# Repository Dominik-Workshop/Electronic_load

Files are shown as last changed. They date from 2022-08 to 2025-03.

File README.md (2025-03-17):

# DC Electronic load

### More info about this project can be found on my channel: 
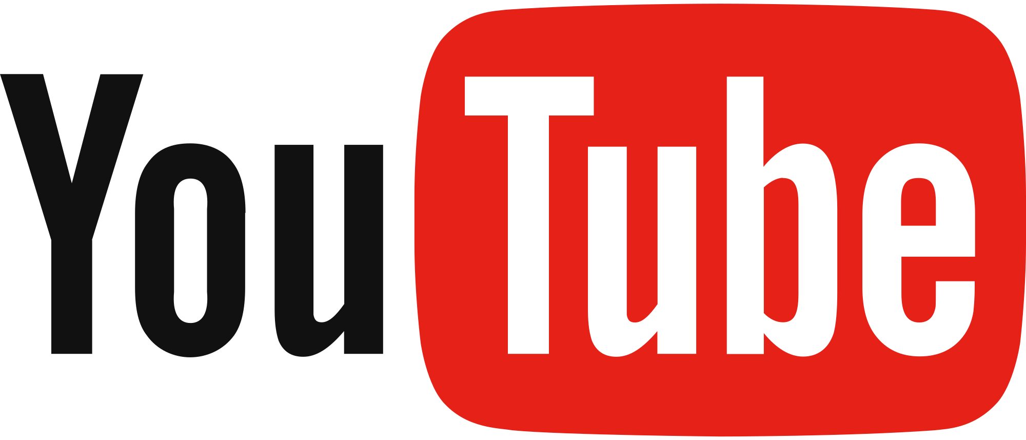
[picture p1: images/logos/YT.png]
 https://youtu.be/NScaRQj53l0

## Used tools:
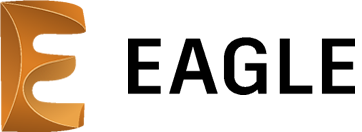
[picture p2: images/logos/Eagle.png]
 &nbsp;&nbsp;&nbsp;&nbsp; &nbsp;&nbsp;&nbsp;&nbsp; 
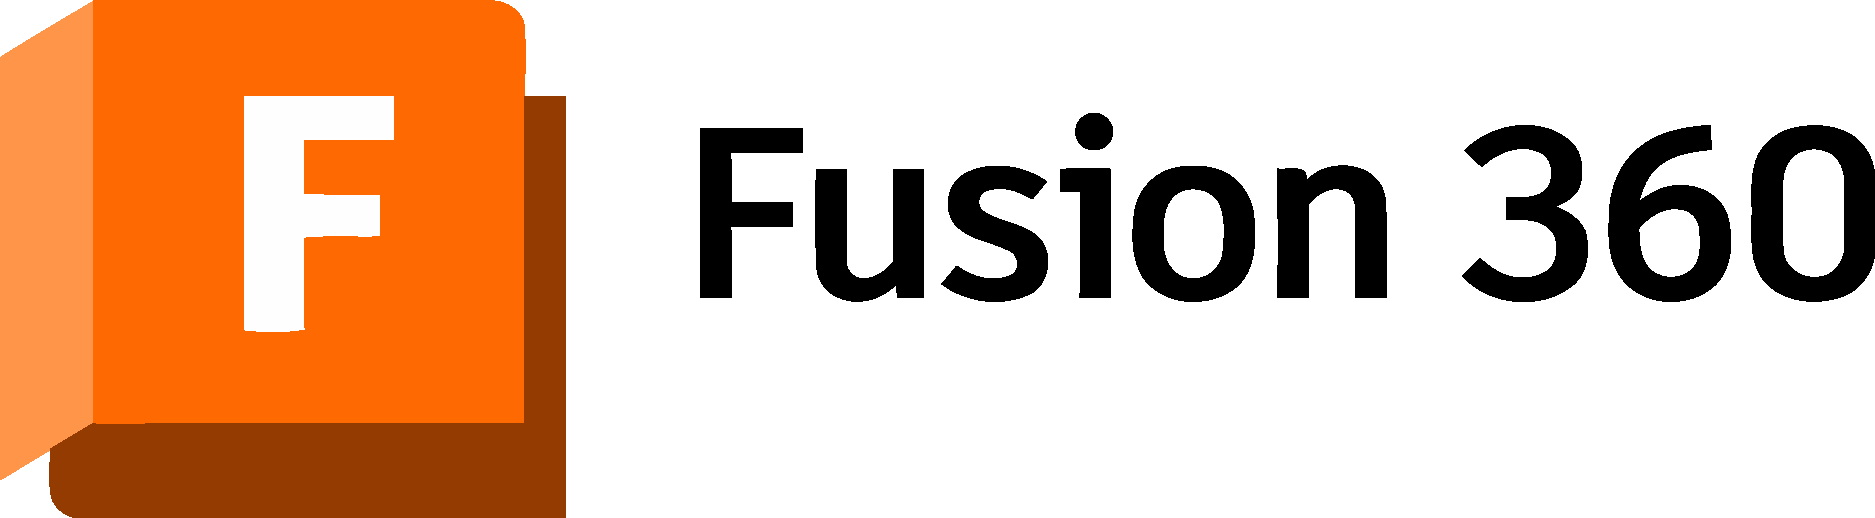
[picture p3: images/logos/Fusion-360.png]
 &nbsp;&nbsp;&nbsp;&nbsp; &nbsp;&nbsp;&nbsp;&nbsp; 
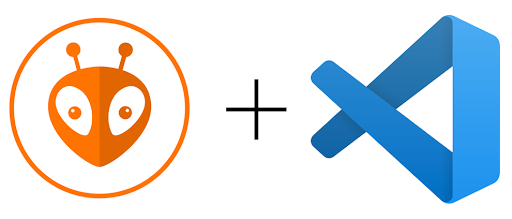
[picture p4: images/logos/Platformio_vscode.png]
 &nbsp;&nbsp; &nbsp;&nbsp;&nbsp;&nbsp; 
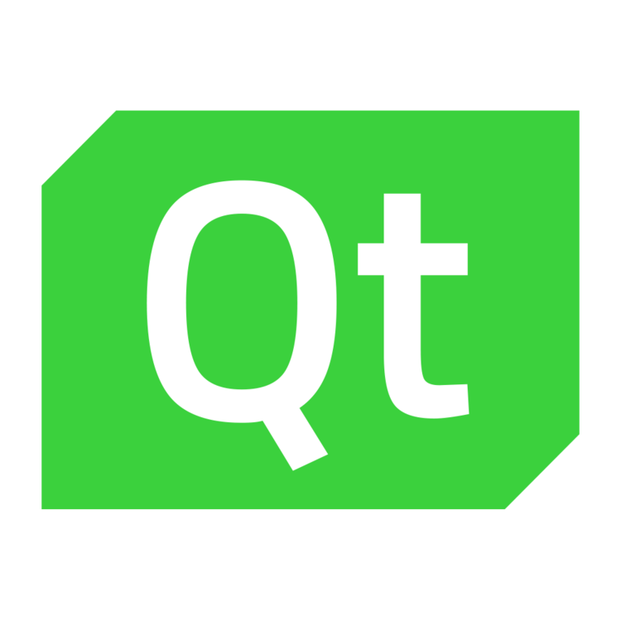
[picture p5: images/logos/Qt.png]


## Project status: :heavy_check_mark: ready for construction!
The project is poised for construction and operational use. However, ongoing development persists, addressing minor bug fixes and introducing new features. Stay tuned for updates!

## Project overview
Commercially available electronic loads often come with a hefty price tag, so I decided to build my own. 
This project was inspired by many electronic loads, with the primary inspiration being Scullcom's Electronic DC Load. You can view it [here](https://www.youtube.com/watch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).

 
&nbsp;&nbsp;&nbsp; 
 

### Project goals:
- **300 W power dissipation**

- **up to 8A and 50V** (obeying the 300W limit)

- **Remote voltage sensing option**

- **Easy to input values:** you can use an encoder as well as a keypad

- **5 modes of operation**
  - **Constant current mode**

  - **Constant power mode**

  - **Constant resistance mode**

  - **Transient response mode**

  - **Battery testing mode**

- **Nice to look at:** doesn't look like a poor DIY build

## Electronics:
### Block diagram



### PCBs:
- Main board: responsible for main funcionalities of the load

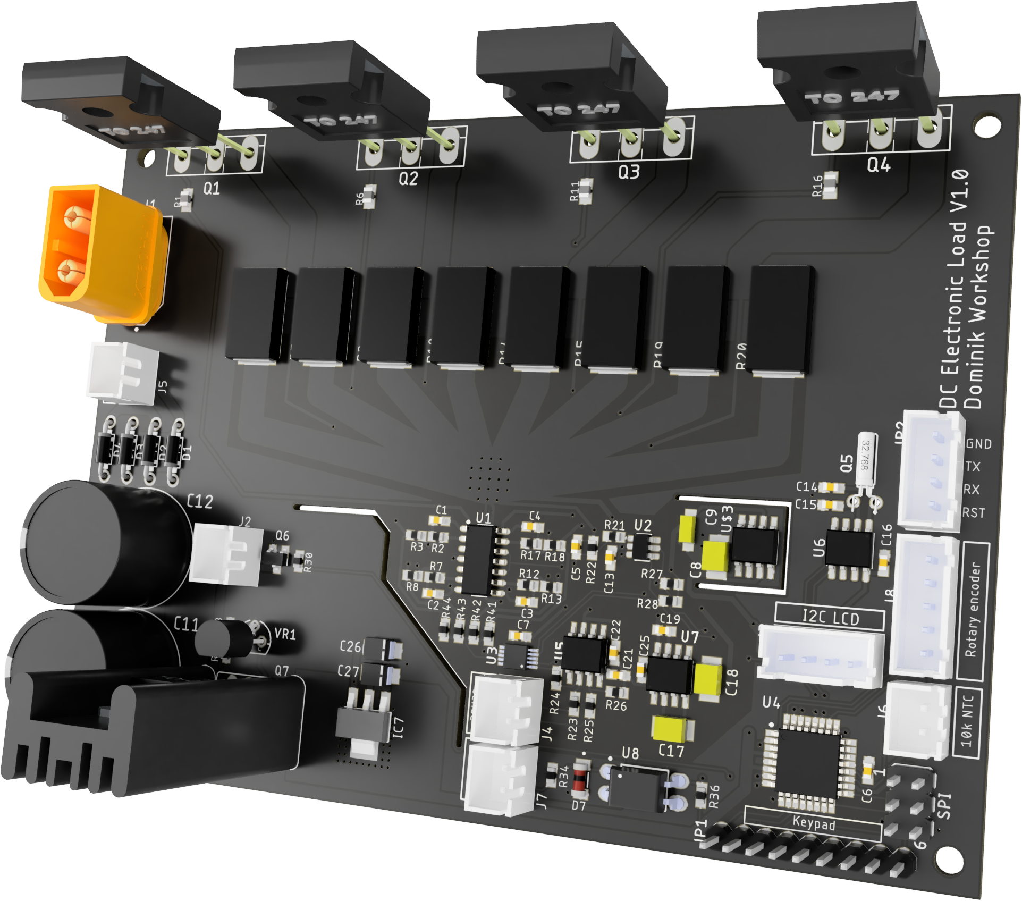
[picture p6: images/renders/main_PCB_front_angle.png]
 

- Front board: responsible for user input with the rotary encoder and switching the voltage measurement circuitry between the main and sense terminals

<p align="center">
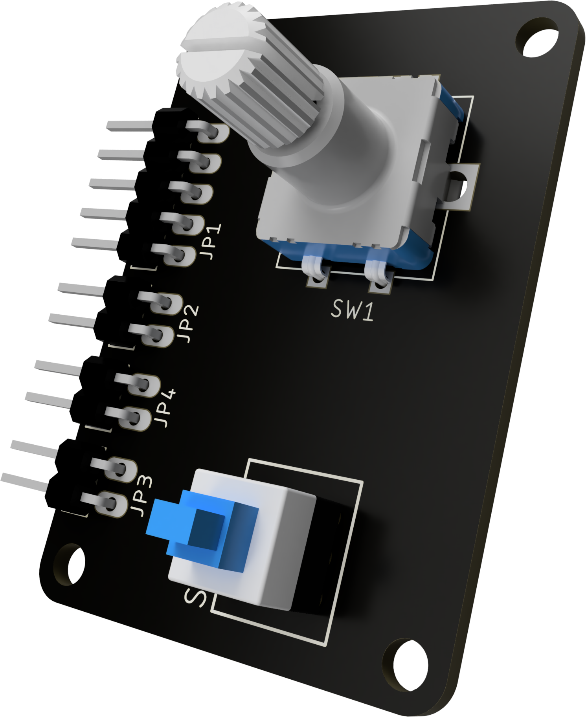
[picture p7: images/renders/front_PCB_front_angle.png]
   
</p>

## Mechanical construction:
The case for this project is made with 1mm thick bent sheet metal, with a 3D printed front panel.

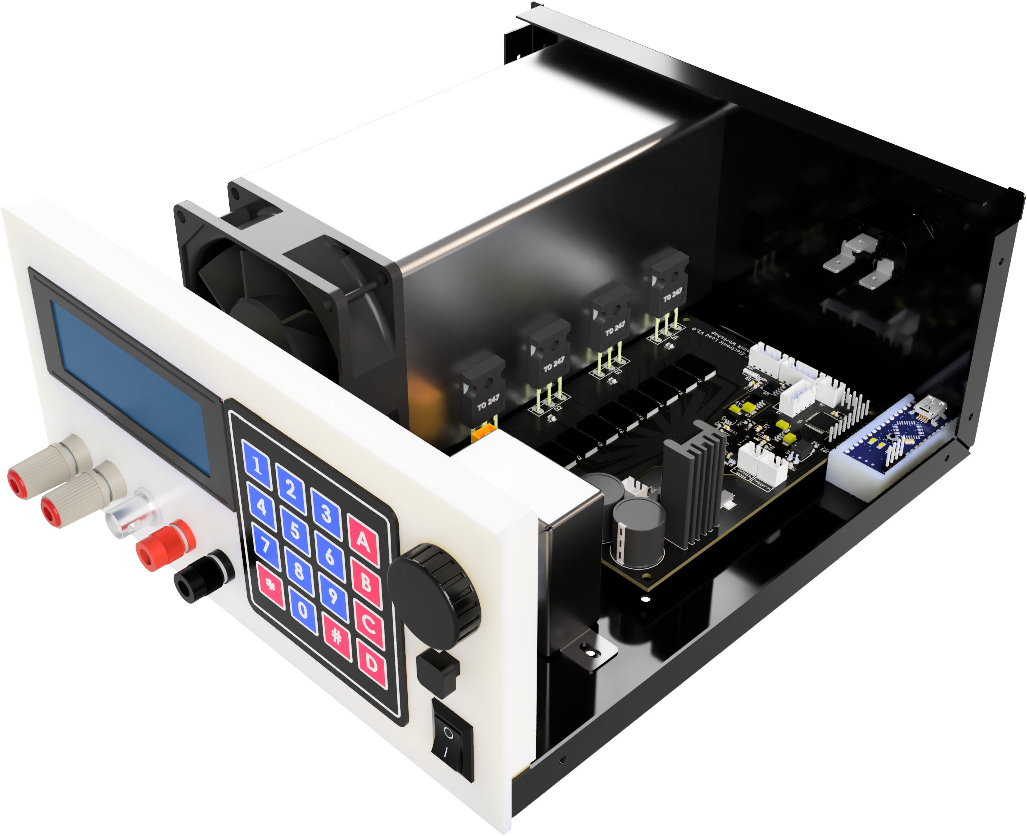
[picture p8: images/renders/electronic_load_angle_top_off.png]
 
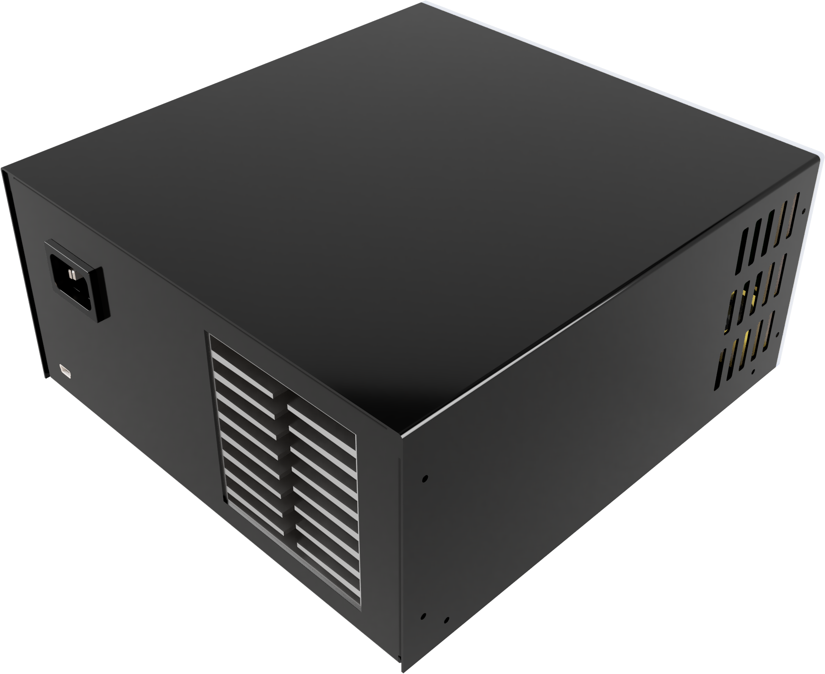
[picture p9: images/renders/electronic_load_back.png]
 

## PC remote controll battery mode app
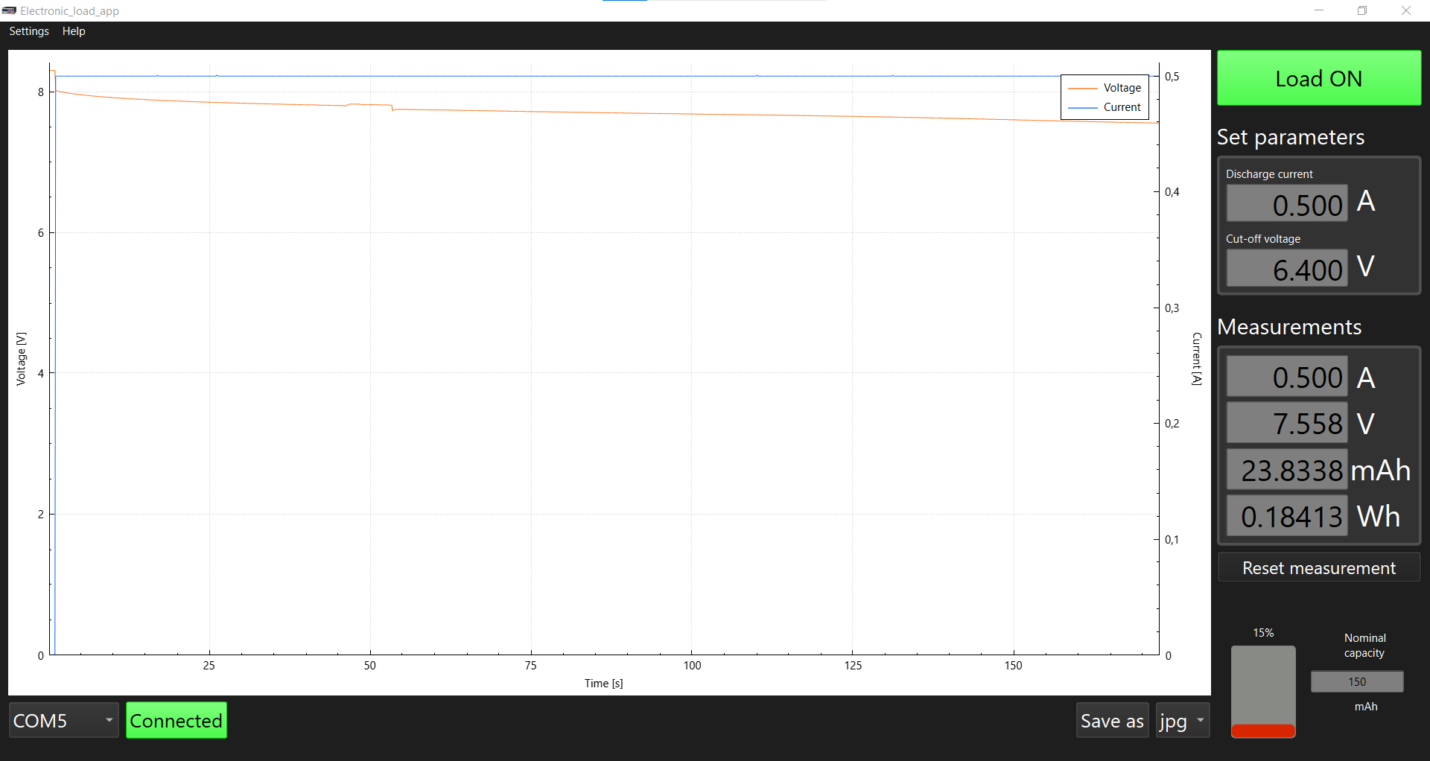
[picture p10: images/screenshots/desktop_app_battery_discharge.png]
 
The app is currently available for Windows only. To run it, simply double-click on

`\desktop_app\release\windows-64bit\electronic_load_control_app.exe`

## Accuracy measurements
<details>
<summary>Click to learn more</summary>

The precision of the electronic load's current and voltage measurements, as well as its set current accuracy, were tested against the `Sanwa PC7000` multimeter. The following tables present the results of these measurements.

### Accuracy of set and measured current values

| Set Value [A] | Load Measurement [A] | Multimeter Measurement [A]  |
|:---|:---|:---|
| 0.1 | 0.104 | 0.1032 ± 0.0029 |
| 0.2 | 0.203 | 0.2024 ± 0.0037 |
| 0.3 | 0.300 | 0.3000 ± 0.0044 |
| 0.4 | 0.406 | 0.4051 ± 0.0053 |
| 0.5 | 0.500 | 0.4997 ± 0.0060 |
| 0.6 | 0.602 | 0.6020 ± 0.0069 |
| 0.7 | 0.702 | 0.7020 ± 0.0077 |
| 0.8 | 0.800 | 0.8000 ± 0.0084 |
| 0.9 | 0.904 | 0.9038 ± 0.0093 |
| 1.0 | 1.007 | 1.0065 ± 0.0101 |
| 2.0 | 2.007 | 2.0070 ± 0.0181 |
| 3.0 | 3.006 | 3.0057 ± 0.0261 |
| 4.0 | 4.003 | 4.0022 ± 0.0341 |
| 5.0 | 5.002 | 5.0007 ± 0.0421 |
| 6.0 | 6.001 | 5.996 ± 0.068 |
| 7.0 | 6.998 | 6.997 ± 0.076 |
| 8.0 | 7.998 | 7.990 ± 0.084 |

### Accuracy of voltage measurements

| Load Measurement [V] | Multimeter Measurement [V] |
|:---|:---|
| 1.002 | 1.0022 ± 0.0006 |
| 2.002 | 2.0029 ± 0.0009 |
| 3.004 | 3.0043 ± 0.0012 |
| 4.004 | 4.0039 ± 0.0015 |
| 5.006 | 5.0058 ± 0.0018 |
| 8.004 | 8.004 ± 0.006 |
| 10.01 | 10.007 ± 0.007 |
| 12.01 | 12.008 ± 0.007 |
| 14.01 | 14.010 ± 0.008 |
| 16.01 | 16.004 ± 0.009 |
| 18.01 | 18.007 ± 0.010 |
| 20.01 | 20.008 ± 0.011 |
| 25.01 | 25.011 ± 0.013 |
| 30.02 | 30.016 ± 0.015 |
| 35.02 | 35.019 ± 0.017 |
| 40.02 | 40.019 ± 0.019 |
| 45.02 | 45.023 ± 0.021 |
| 50.01 | 50.012 ± 0.023 |

### Conclusion: ✅

The current values measured by the electronic load did not deviate from the set value by more than **7 mA**. All measurements taken by the electronic load are within the range of values measured by the multimeter, considering the multimeter's measurement error.
</details>

## Uploading the code using USBASP
<details>
<summary>Click to learn more</summary>

Add the following code to the `platformio.ini` file

    upload_protocol = custom
    upload_port = usb
    upload_flags = 
        -C
        ${platformio.packages_dir}/tool-avrdude/avrdude.conf
        -p
        $BOARD_MCU
        -P
        $UPLOAD_PORT
        -c
        usbasp
    upload_command = avrdude $UPLOAD_FLAGS -U flash:w:$SOURCE:i

Uploading the code this way will reduce the boot up time.

**Note:** Since this method removes the bootloader, in order to program the uC via UART next time, you have to burn the bootloader.
</details>

## What could be improved in the next version:
  - Add reverse polarity protection
  - Higher resolution DAC

## Special thanks

Special thanks to [**Eryk Możdzeń**](https://github.com/Eryk-Mozdzen), who helped solving a software problem with a memory leak.

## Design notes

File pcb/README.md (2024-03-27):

## Main board

<p align="center">
  
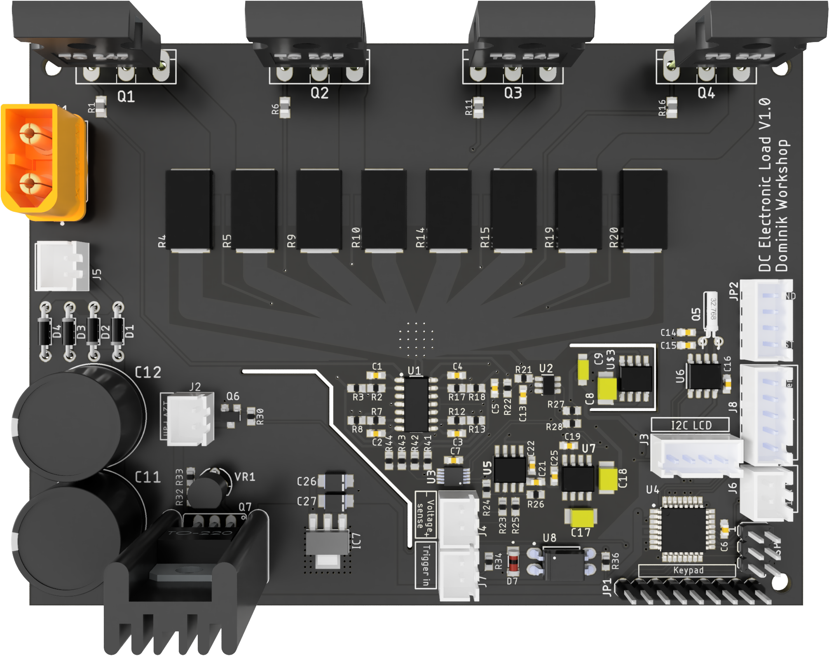
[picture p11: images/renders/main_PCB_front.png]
  
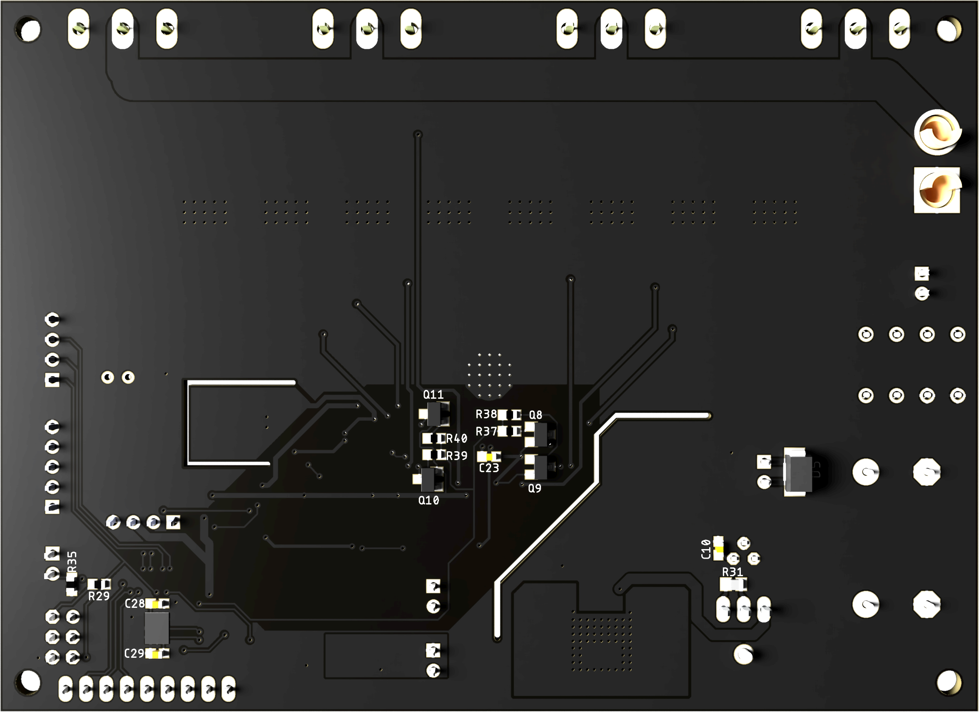
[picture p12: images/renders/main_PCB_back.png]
  
</p>

## Front board

<p align="center">
  
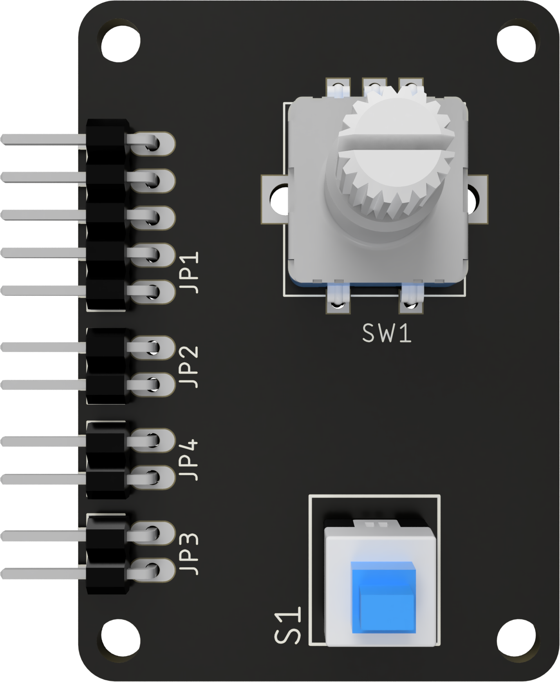
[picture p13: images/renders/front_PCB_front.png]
  
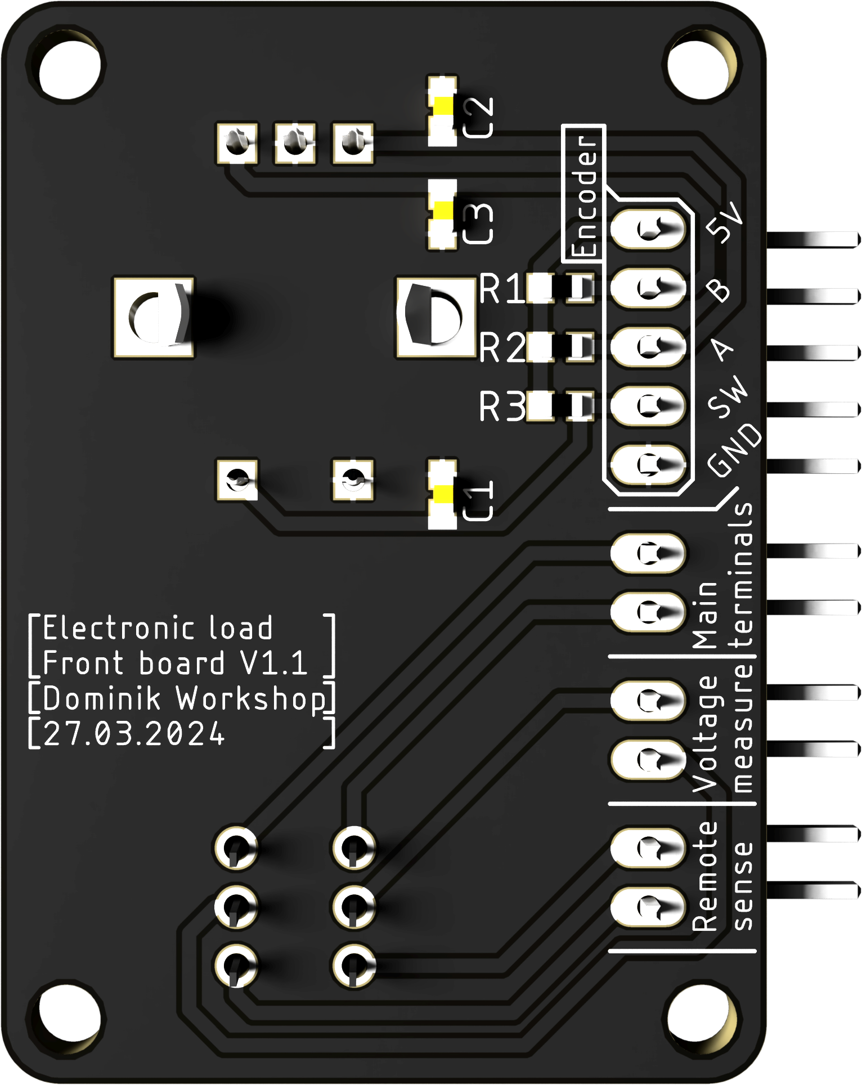
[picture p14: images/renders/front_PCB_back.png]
  
</p>

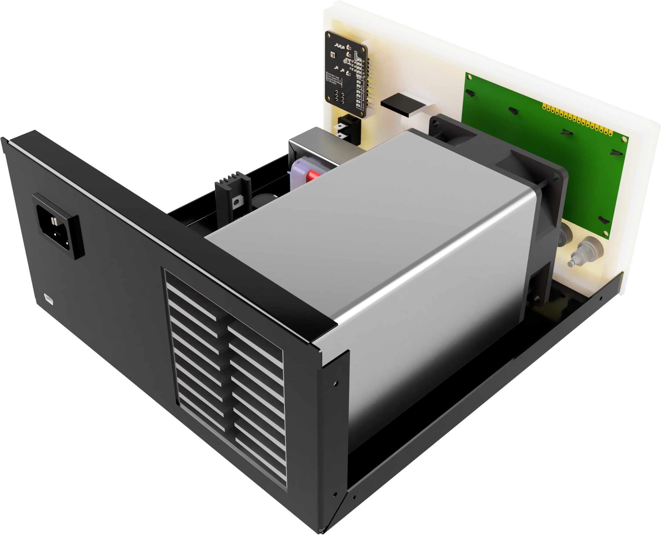
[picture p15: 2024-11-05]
images/renders/electronic_load_back_top_off.png

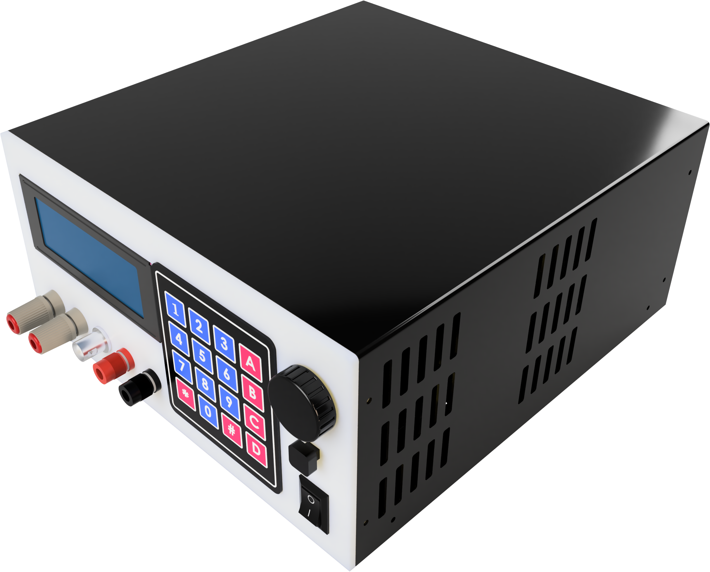
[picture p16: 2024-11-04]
images/renders/electronic_load_angle.png

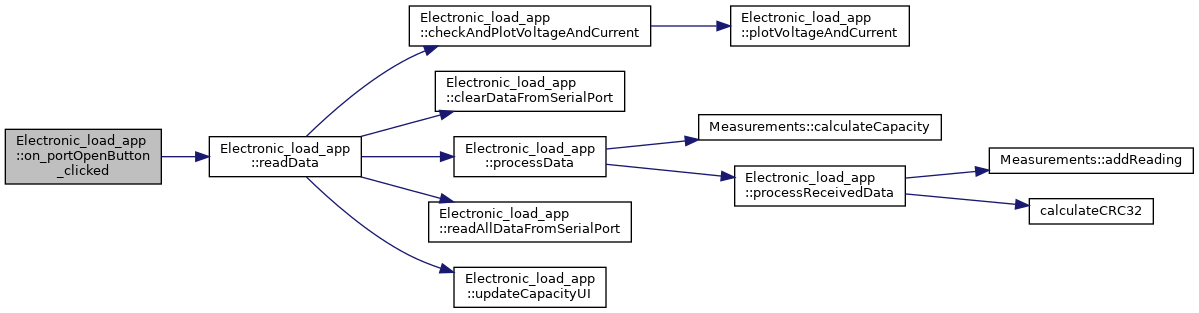
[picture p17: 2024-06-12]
desktop_app/dox/html/class_electronic__load__app_afe7a07bc97dab9acf673cdcb3675695e_cgraph.png

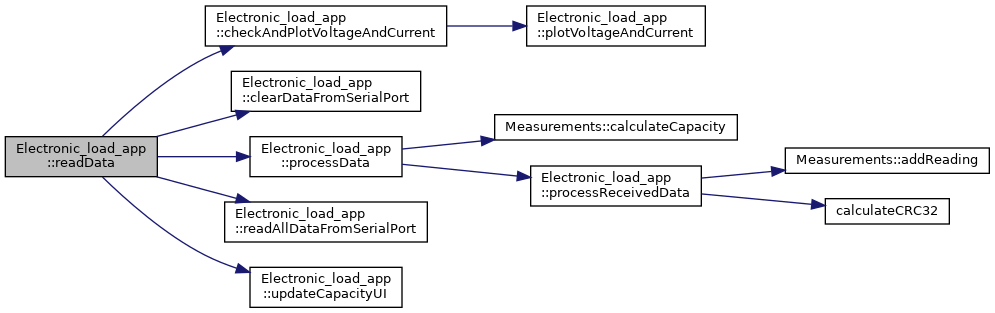
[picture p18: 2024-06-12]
desktop_app/dox/html/class_electronic__load__app_a9539f558719b2edaba668095b3a171cb_cgraph.png

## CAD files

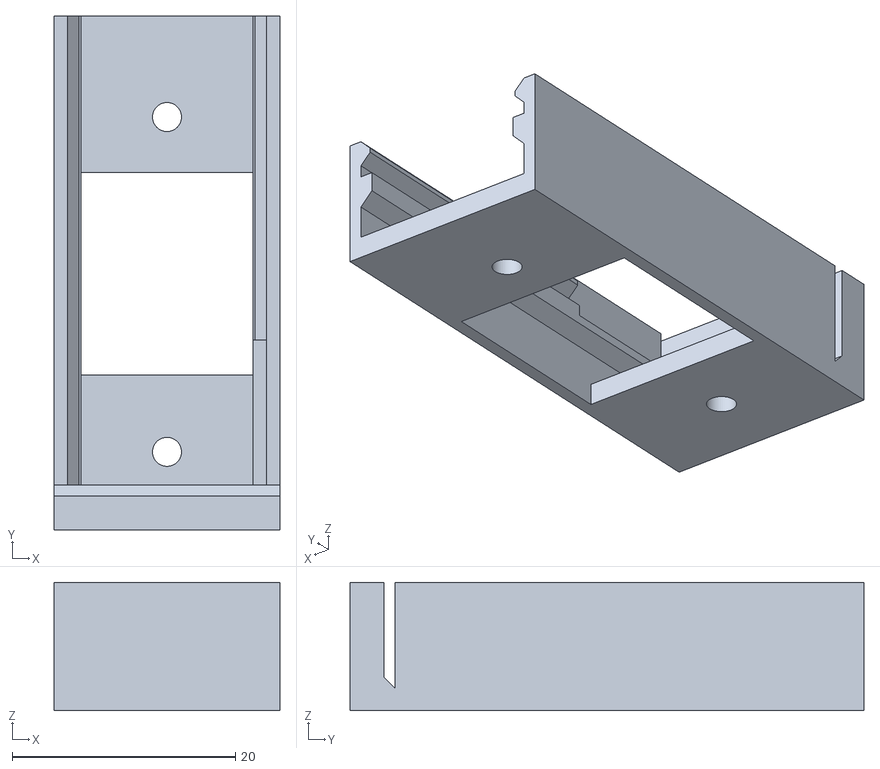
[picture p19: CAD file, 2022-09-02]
3d_models/arduino_holder.stl
20.2 x 46.1 x 11.5

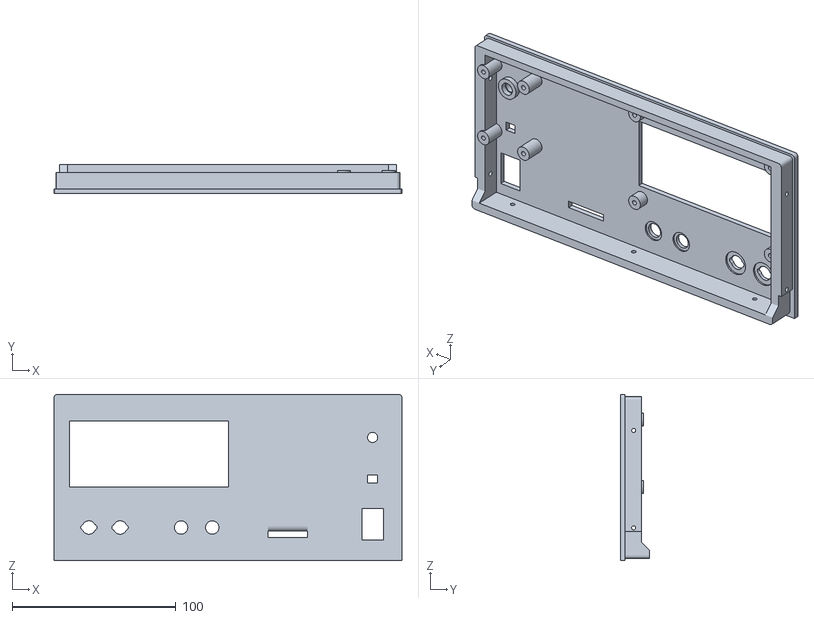
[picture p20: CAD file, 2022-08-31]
3d_models/front_pannel.stl
212.6 x 18.0 x 101.5

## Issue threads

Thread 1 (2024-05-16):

Update battery max capacity and time.

marecek89, 2024-05-16:
How and where in the program should the increase in the maximum capacity of the measured battery be adjusted ? for example, I want to test a battery of 15000 mah and maybe higher than 100,000mah. What happens to the time when it reaches 99 hours? Thanks

Dominik-Workshop, 2024-05-31:
In `battery.cpp`, line 26 there is `dtostrf(capacity, 5, 0, displayValue);`. The 5 represents the maximum amount of digits for the capacity measurements, so to measure capacities higher than 99.999mAh you have to change it to 6.
When it comes to the timer, I suppose it just overflows to 00:00:00 (not tested), but I guess 99h should be enough to complete the measurement.
Let me know if you need further clarification or assistance with the adjustments.
I'm sorry for my late reply.

marecek89, 2024-06-04:
In mode_screen.hh line 84 it is not necessary to add ``0'' to the display ? I'm looking forward to when the program is ready. Will it be necessary to upload a program to the tester so that it works with a PC?

Dominik-Workshop, 2024-06-04:
Line 84 in `mode_screen.hh` is just a comment to help when coding, so it doesn't matter, if that's what you mean.
The desktop app is now ready to use for windows, I just need to merge it to `master` and provide some installation and usage instructions (I'm just low on time recently). But you can test it already by going to branch `remote_app` and cloning/dowloading the repository.
Yes, you have to upload the new code to the Electronic Load for it to work with the PC program.
To open the PC app you just have to open `desktop_app/release/windows-64bit/electronic_load_app.exe`. There is no installation required.
If you decide to check it out, please let me know if it works!

marecek89, 2024-06-25:
I tested the initial version of the app. The app works fine. when displaying the graph and line, the highest value is displayed at the very top. it could be adjusted so that the scale moves a little more so that the top line is not parallel to the top ?

Dominik-Workshop, 2024-06-25:
Thank you for testing it; it's nice to hear that it works.
You can uncheck the Plot from zero option in the settings to achieve the following result:
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
Is this what you wanted to achieve?
The scale can't be moved arbitrarily, at least for now.

marecek89, 2024-06-25:
the current scale obviously changes with the addition of current. in your example, the blue line is, for example, at the value 4 and it is high.. if, for example, the graph was at a value of 4A, the scale would be 1A more so that it would be clearer and more visible. I don't know if you understood me

Dominik-Workshop, 2024-06-27:
Oh, ok, I think I understand now. I might consider this in future updates.

Closed 2024-10-26.

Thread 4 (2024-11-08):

Calibration

yo8ssv, 2024-11-08:
Hi,

Can you describe procedure for calibration? I'm trying to do but with out succes. I enabled memu 6 for calibration and when I compile it say that is greater than flash size. How it can be done, please.

Thank you

Dominik-Workshop, 2024-11-08:
Hello.

Seems like the recently added feature took up the remaninig space. You can easily solve this issue by commenting other functions in main.cpp, for example batteryMeasurement() and transient(). This should provide enough space in uC's memory. When you are done with calibration, you can uncomment these functions and comment calibration().

Hope it helps.

yo8ssv, 2024-11-08:
Ok, and how to save at the end of calibration procedure? It ask for yes or no, which button is yes and no?

Dominik-Workshop, 2024-11-08:
Yes - Enter
No - Delete.
(It should be written on the LCD)

Dominik-Workshop, 2025-03-30:
Posted [calibration guide](https://youtu.be/jx0t7Ovq4uw?si=9ajka1ZFl43V9Rm9) on YouTube.

Closed 2024-11-13.

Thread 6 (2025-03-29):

Generate PCB renders

Dominik-Workshop, 2025-03-29:
Generate PCB renders using `Blender`.

Dominik-Workshop, 2025-03-30:
Generated a `Blender` model of the `PCB` with solder on pads, using [gerber2blend](https://github.com/antmicro/gerber2blend) and placed  most components using [picknblend](https://github.com/antmicro/picknblend). Required manual matching of components to those in [hardware-components](https://github.com/antmicro/hardware-components), which involved renaming entries in the `positional file`. The remaining components are not present in the library, and their models will likely need to be manually added to the `Blender model`."

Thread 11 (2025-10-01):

Problem with battery capacity measurement.

marecek89, 2025-10-01:
Hi, I have built your project which you helped me set up and calibrate. The problem occurred when testing a 12V70Ah battery. The current drawn was set to 3.5A. During the measurement, the recorded capacity was initially displayed correctly, but then at 14 hours the value 4196981200mAh was displayed. I tried adding the value deletion on the display but with another battery I recorded 31188mAh after 8 hours of discharge, then at 17 hours 48 minutes the value was 419663027mAh which is an unrealistic value. Can you advise me what could be causing this? Even if the battery was good, the time should last 20 hours and the capacity should be around 70000mAh which should not be a problem but there is probably a mistake somewhere and I can't find it. Thank you

marecek89, 2025-10-07:
Hi, I tried using millis to track time during a capacity test but the adjustment was unsuccessful. After 7 hours of testing, the time was 4 minutes late and I didn't like that. I decided to use rtc but only a second interval and then calculate the time. I currently have a modified version that has been running for 22 hours. So far everything looks ok. I plan to let the test run for 100 hours to see if it is able to measure such a time with this adjustment. If the tests pass, I will send you the modified code so you can go through it and check it. I have a question, is rtc time only used in the battery function? I think transient uses millis. Or is rtc still used somewhere besides measuring capacity? Thank you

Dominik-Workshop, 2025-10-07:
I'm thrilled to hear that you managed to fix the problem. I hope the long term test passes.
Thank you very much for your valuable input.

---
Yes, RTC is only used in the 'batteryCapacityMode()' and I'm using 'millis()'  in transient mode (which isn't a perfect solution)

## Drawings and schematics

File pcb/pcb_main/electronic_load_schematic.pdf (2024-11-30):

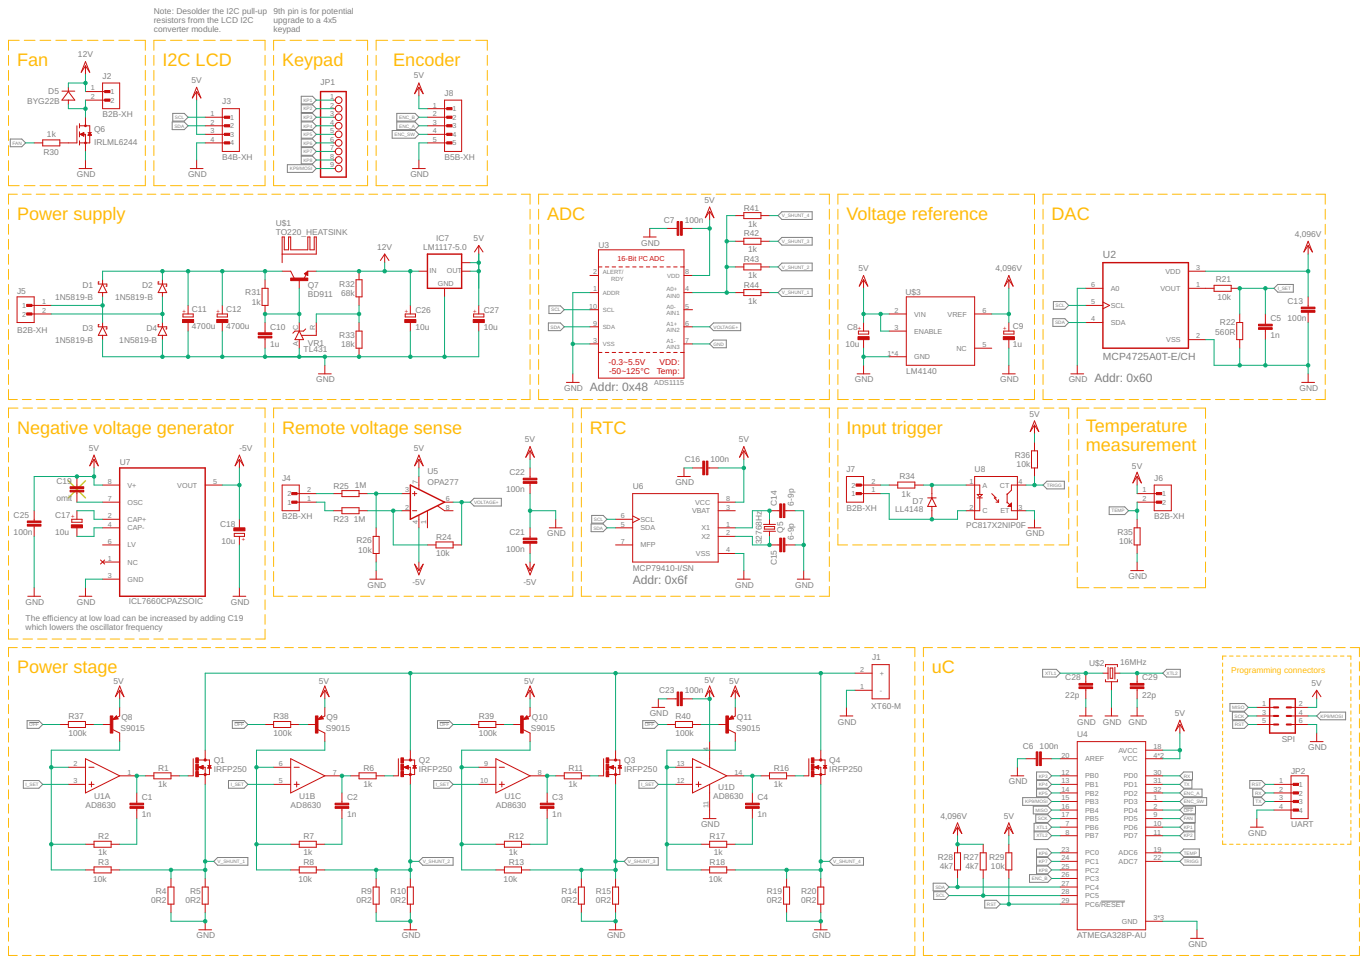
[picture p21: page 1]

Note: Desolder the I2C pull-up
resistors from the LCD I2C
converter module.

9th pin is for potential upgrade to a 4x5

The efficiency at low load can be increased by adding C19 which lowers the oscillator frequency

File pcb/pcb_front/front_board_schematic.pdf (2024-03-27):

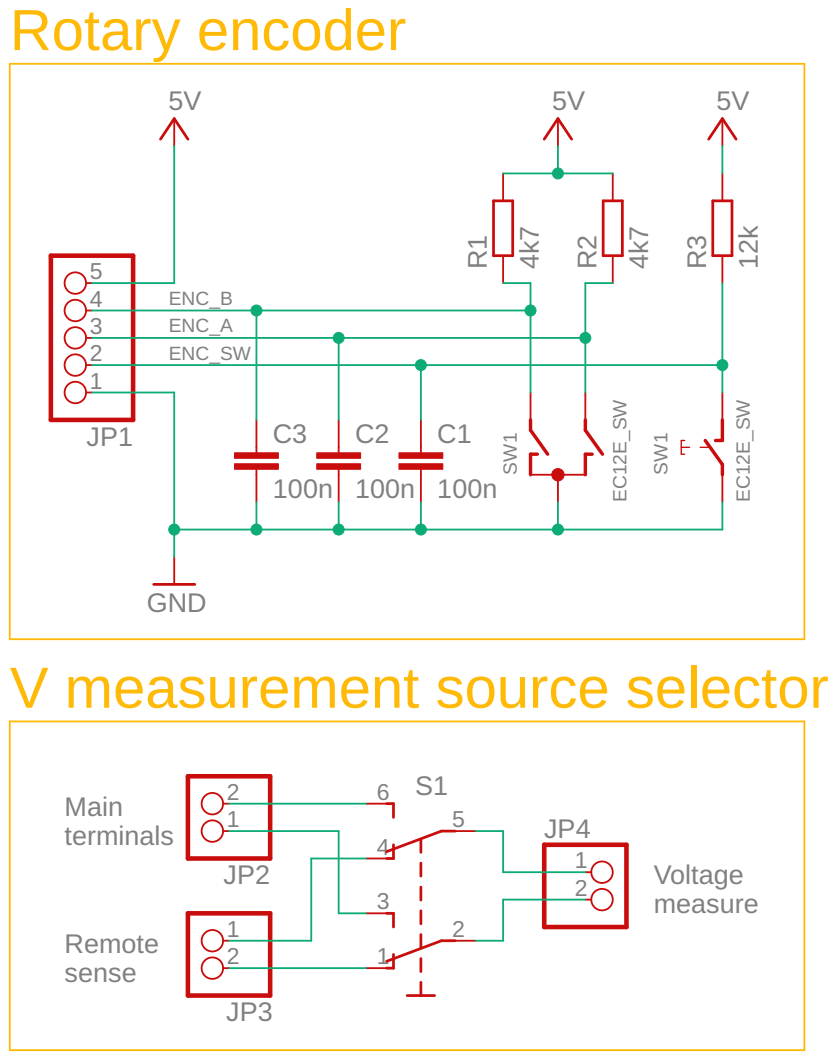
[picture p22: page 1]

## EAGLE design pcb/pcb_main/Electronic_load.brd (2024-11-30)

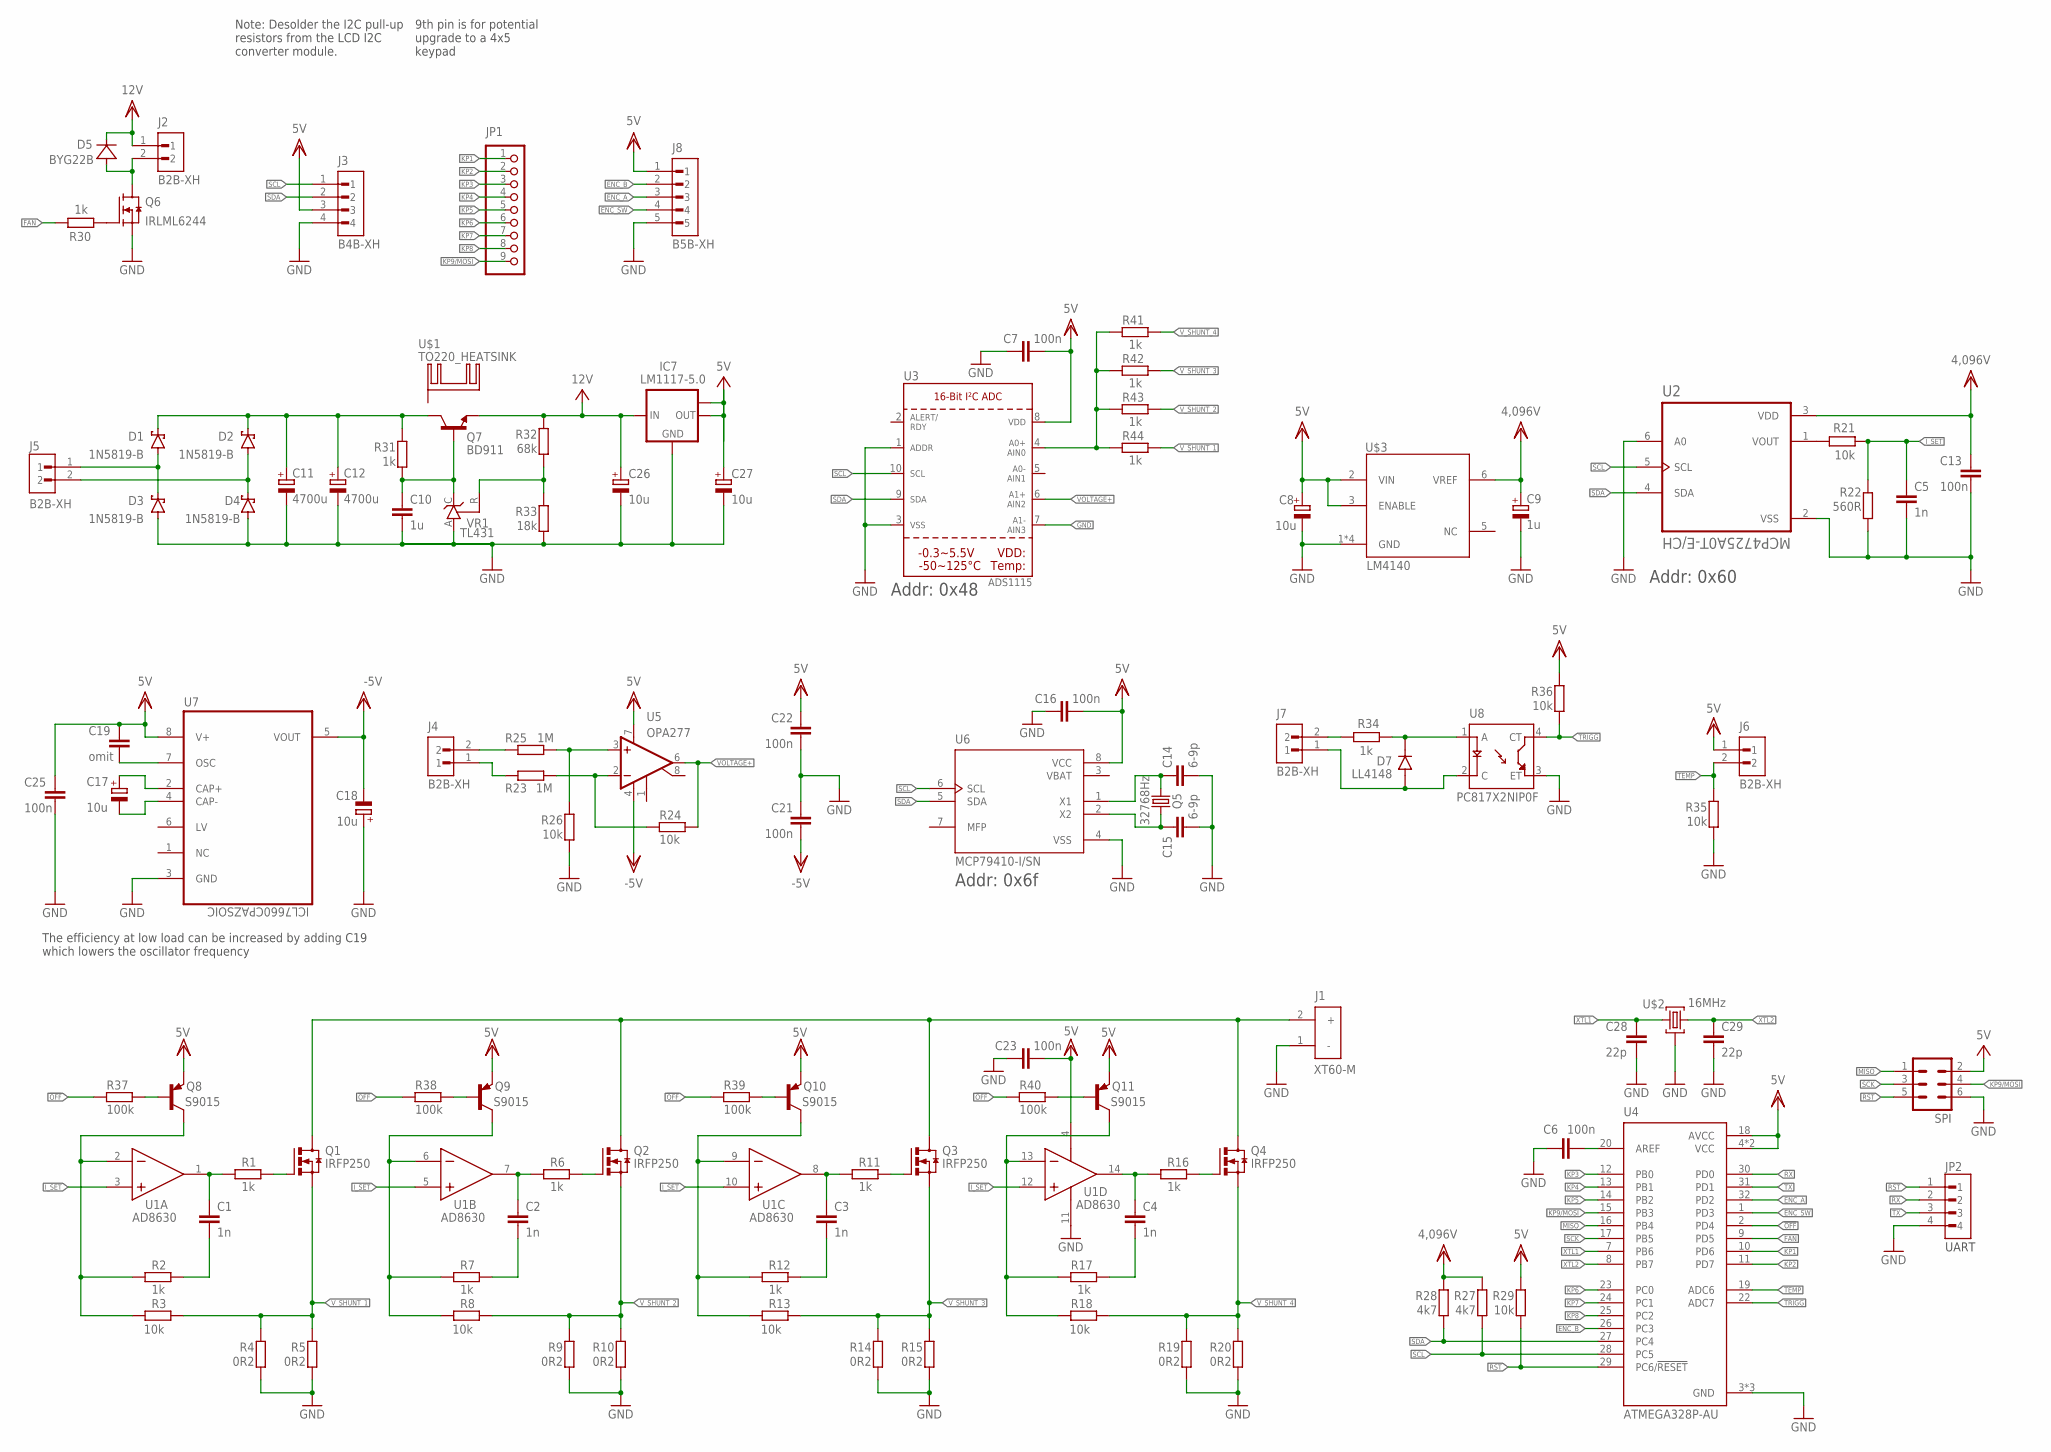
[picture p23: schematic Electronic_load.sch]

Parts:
C1, C2, C3, C4, C5: 1n; C0603
C6, C7, C13, C16, C21, C22, C25: 100n; C0603
C8, C17, C18: 10u; CT3528
C9: 1u; CT3216
C10: 1u; C0603
C11, C12: 4700u; E7,5-16
C14, C15: 6-9p; C0603
C19: omit; C0603
C23: 100n; C0603K
C26, C27: 10u; B/3528-21W
C28, C29: 22p; C0603
D1, D2, D3, D4: 1N5819-B; DO41-7.6
D5: BYG22B; DO-214AC
D7: LL4148; DIOMELF3515N
IC7: LM1117-5.0; SOT223
J1: XT60-M; AMASS_XT60-M
J2, J4, J5, J6, J7: B2B-XH; JST_B2B-XH-A(LF)(SN)
J3: B4B-XH; JST_B4B-XH-A(LF)(SN)
J8: B5B-XH; JST_B5B-XH-A(LF)(SN)
JP1: PINHD-1X9; 1X09
JP2: B4B-XH; JST_B4B-XH-A(LF)(SN)
Q1, Q2, Q3, Q4: IRFP250; TO-247AD-V
Q5: 32768Hz; TC26H
Q6: IRLML6244; SOT23
Q7: BD911; TO220V
Q8, Q9, Q10, Q11: S9015; SOT23
R1, R6, R11, R16, R31: 1k; R0805
R2, R7, R12, R17, R30, R34, R41, R42, R43, R44: 1k; R0603
R3, R8, R13, R18, R21, R24, R26, R29, R35, R36: 10k; R0603
R4, R5, R9, R10, R14, R15, R19, R20: 0R2; R4527
R22: 560R; R0603
R23, R25: 1M; R0603
R27, R28: 4k7; R0603
R32: 68k; R0603
R33: 18k; R0603
R37, R38, R39, R40: 100k; R0603
SPI: MA03-2
U1: ANALOG_DEVICES_AD8630ARZ-REEL7ANALOG_DEVICES_AD86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; ANALOG_DEVICES_AD8630ARZ-REEL7_0
U2: MCP4725A0T-E/CH; SOT95P270X145-6N
U3: ADS1115; MSOP10
U4: ATMEGA328P-AU; QFP80P900X900X120-32N
U5: OPA277; SOIC-08_150MIL
U6: MCP79410-I/SN; SOIC127P600X175-8N
U7: ICL7660CPAZSOIC; SOIC8
U8: PC817X2NIP0F; SOT254P975X400-4N
U$1: TO220_HEATSINK
U$2: 16MHz; CRYSTAL_3,4X2,7
U$3: LM4140; SOIC8
VR1: TL431; TO92-CLP

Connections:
4,096V: C9.+, C13.1, R27.1, R28.1, U2.3 (VDD), U$3.6 (VREF)
5V: C7.1, C8.+, C16.1, C19.1, C22.2, C23.1, C25.1, C27.+, IC7.2 (OUT), IC7.TAB (OUT1), J3.3, J6.1, J8.1, Q8.2 (E), Q9.2 (E), Q10.2 (E), Q11.2 (E), R29.1, R36.2, SPI.2, U1.4 (+V), U3.8 (VDD), U4.4 (VCC), U4.6 (VCC), U4.18 (AVCC), U5.7 (V+), U6.8 (VCC), U7.8 (V+), U$3.2 (VIN), U$3.3 (ENABLE)
12V: C26.+, D5.C, IC7.3 (IN), J2.1, Q7.3 (E), R32.1
16V: C11.+, C12.+, D1.C, D2.C, Q7.2 (C), R31.1
!OFF: R37.1, R38.1, R39.1, R40.1, U4.2 (PD4)
-5V: C18.-, C21.1, U5.4 (V-), U7.5 (VOUT)
AREF: C6.1, U4.20 (AREF)
BASE: C10.1, Q7.1 (B), R31.2, VR1.C
CURRENT: R41.1, R42.1, R43.1, R44.1, U3.4 (AIN0)
DAC_OUT: R21.2, U2.1 (VOUT)
ENC_A: J8.3, U4.32 (PD2)
ENC_B: J8.2, U4.26 (PC3)
ENC_SW: J8.4, U4.1 (PD3)
FAN: R30.1, U4.9 (PD5)
GND: C5.2, C6.2, C7.2, C8.-, C9.-, C10.2, C11.-, C12.-, C13.2, C14.2, C15.2, C16.2, C18.+, C21.2, C22.1, C23.2, C25.2, C26.-, C27.-, C28.2, C29.2, D3.A, D4.A, IC7.1 (GND), J1.1 (-), J3.4, J8.5, JP2.4, Q6.2 (S), R4.1, R5.1, R9.1, R10.1, R14.1, R15.1, R19.1, R20.1, R22.2, R26.1, R33.2, R35.1, SPI.6, U1.11 (-V), U2.2 (VSS), U2.6 (A0), U3.1 (ADDR), U3.3 (VSS), U3.7 (AIN3), U4.3 (GND), U4.5 (GND), U4.21 (GND), U6.4 (VSS), U7.3 (GND), U8.3 (ET), U$2.GND (2), U$2.GND2 (2), U$3.1 (GND), U$3.4 (GND), U$3.7 (GND), U$3.8 (GND), VR1.A
I_SET: C5.1, R21.1, R22.1, U1.3 (+IN_A), U1.5 (+IN_B), U1.10 (+IN_C), U1.12 (+IN_D)
KP1: JP1.1, U4.10 (PD6)
KP2: JP1.2, U4.11 (PD7)
KP3: JP1.3, U4.12 (PB0)
KP4: JP1.4, U4.13 (PB1)
KP5: JP1.5, U4.14 (PB2)
KP6: JP1.6, U4.23 (PC0)
KP7: JP1.7, U4.24 (PC1)
KP8: JP1.8, U4.25 (PC2)
KP9/MOSI: JP1.9, SPI.4, U4.15 (PB3)
MISO: SPI.1, U4.16 (PB4)
unnamed: D7.C (K), R34.1, U8.1 (A)
unnamed: R25.2, R26.2, U5.3 (+IN)
unnamed: C1.2, R2.2
unnamed: C1.1, R1.1, U1.1 (OUT_A)
unnamed: Q1.G, R1.2
unnamed: Q8.3 (C), R2.1, R3.2, U1.2 (-IN_A)
unnamed: J7.2, R34.2
unnamed: J1.2 (+), Q1.D, Q2.D, Q3.D, Q4.D
unnamed: C2.2, R7.2
unnamed: C2.1, R6.1, U1.7 (OUT_B)
unnamed: Q2.G, R6.2
unnamed: Q8.1 (B), R37.2
unnamed: Q9.3 (C), R7.1, R8.2, U1.6 (-IN_B)
unnamed: R23.2, R24.1, U5.2 (-IN)
unnamed: C3.2, R12.2
unnamed: C3.1, R11.1, U1.8 (OUT_C)
unnamed: Q3.G, R11.2
unnamed: Q10.3 (C), R12.1, R13.2, U1.9 (-IN_C)
unnamed: C4.2, R17.2
unnamed: C4.1, R16.1, U1.14 (OUT_D)
unnamed: Q4.G, R16.2
unnamed: Q11.3 (C), R17.1, R18.2, U1.13 (-IN_D)
unnamed: D5.A, J2.2, Q6.3 (D)
unnamed: J4.2, R25.1
unnamed: J4.1, R23.1
unnamed: D1.A, D3.C, J5.1
unnamed: D2.A, D4.C, J5.2
unnamed: Q6.1 (G), R30.2
unnamed: C17.+, U7.2 (CAP+)
unnamed: C17.-, U7.4 (CAP-)
unnamed: C14.1, Q5.2, U6.1 (X1)
unnamed: C15.1, Q5.1, U6.2 (X2)
unnamed: C19.2, U7.7 (OSC)
unnamed: Q9.1 (B), R38.2
unnamed: R32.2, R33.1, VR1.R
unnamed: Q10.1 (B), R39.2
unnamed: Q11.1 (B), R40.2
RST: JP2.1, R29.2, SPI.5, U4.29 (PC6/!RESET)
RX: JP2.2, U4.30 (PD0)
SCK: SPI.3, U4.17 (PB5)
SCL: J3.1, R27.2, U2.5 (SCL), U3.10 (SCL), U4.28 (PC5), U6.6 (SCL)
SDA: J3.2, R28.2, U2.4 (SDA), U3.9 (SDA), U4.27 (PC4), U6.5 (SDA)
TEMP: J6.2, R35.2, U4.19 (ADC6)
TRIGG: R36.1, U4.22 (ADC7), U8.4 (CT)
TX: JP2.3, U4.31 (PD1)
T_GND: D7.A, J7.1, U8.2 (C)
VBAT: U6.3 (VBAT)
VOLTAGE+: R24.2, U3.6 (AIN2), U5.6 (OUT)
V_SHUNT_1: Q1.S, R3.1, R4.2, R5.2, R44.2
V_SHUNT_2: Q2.S, R8.1, R9.2, R10.2, R43.2
V_SHUNT_3: Q3.S, R13.1, R14.2, R15.2, R42.2
V_SHUNT_4: Q4.S, R18.1, R19.2, R20.2, R41.2
XTL1: C28.1, U4.7 (PB6), U$2.CRST1 (1)
XTL2: C29.1, U4.8 (PB7), U$2.CRST2 (3)

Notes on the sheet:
Addr: 0x48
Addr: 0x60
Addr: 0x6f
The efficiency at low load can be increased by adding C19 which lowers the oscillator frequency
9th pin is for potential upgrade to a 4x5 keypad
UART
Note: Desolder the I2C pull-up resistors from the LCD I2C converter module.

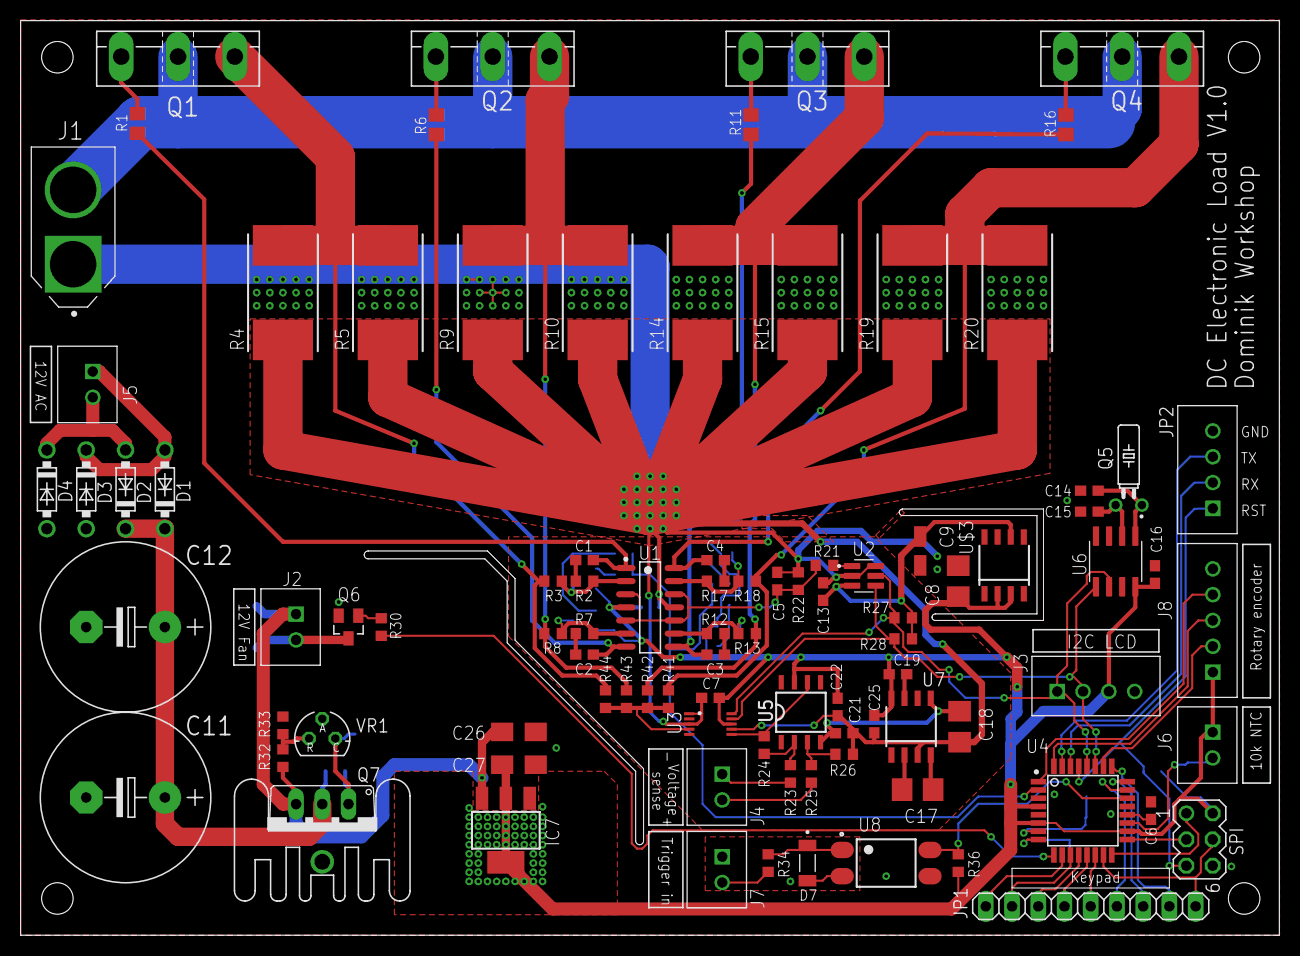
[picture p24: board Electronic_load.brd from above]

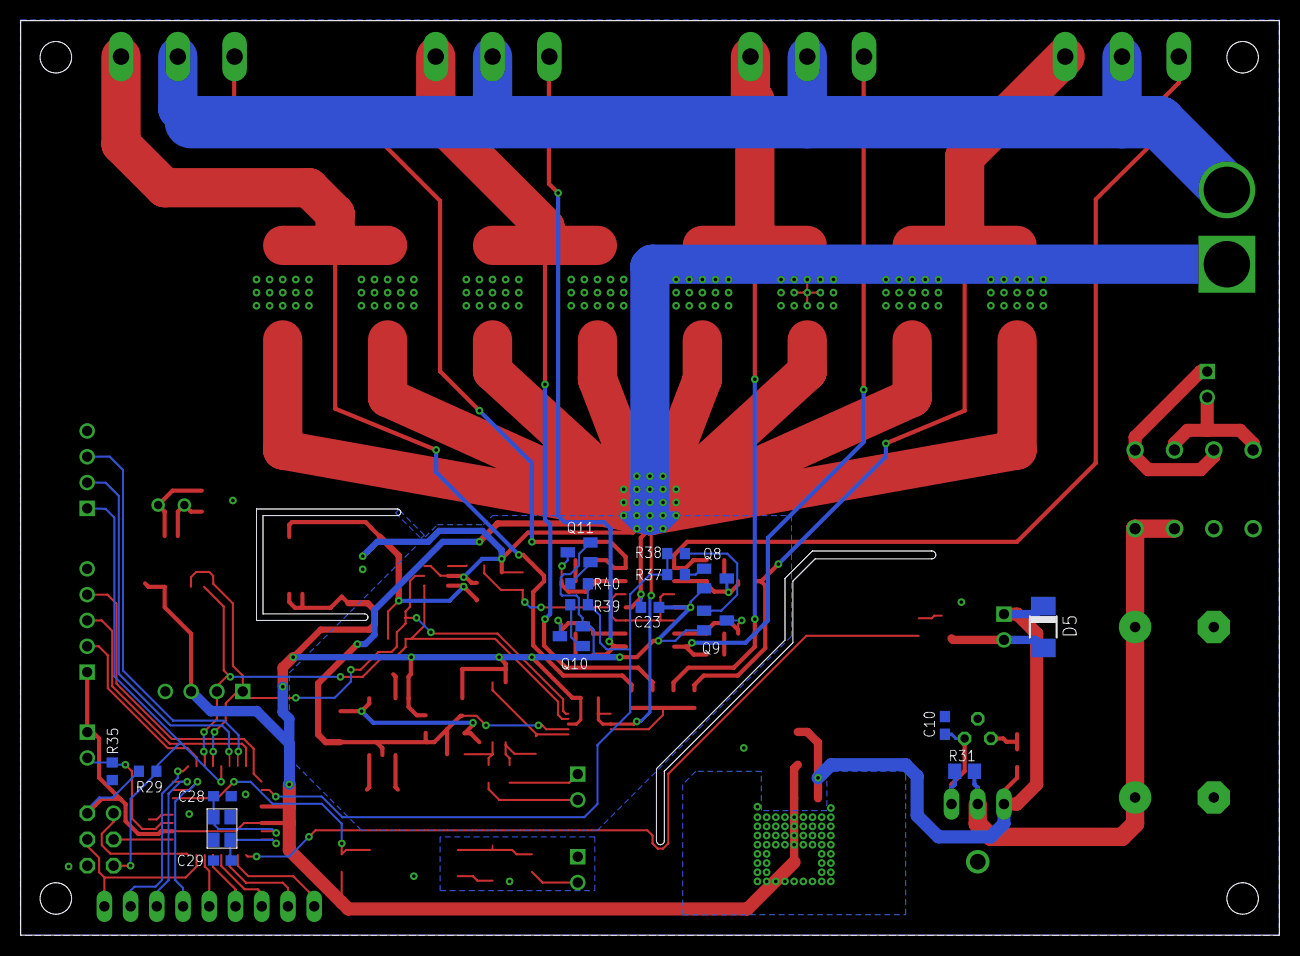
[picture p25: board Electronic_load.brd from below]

Board: 2 copper layers, 121.9 x 88.6 mm, 112 parts (17 on the bottom side), 79 nets.

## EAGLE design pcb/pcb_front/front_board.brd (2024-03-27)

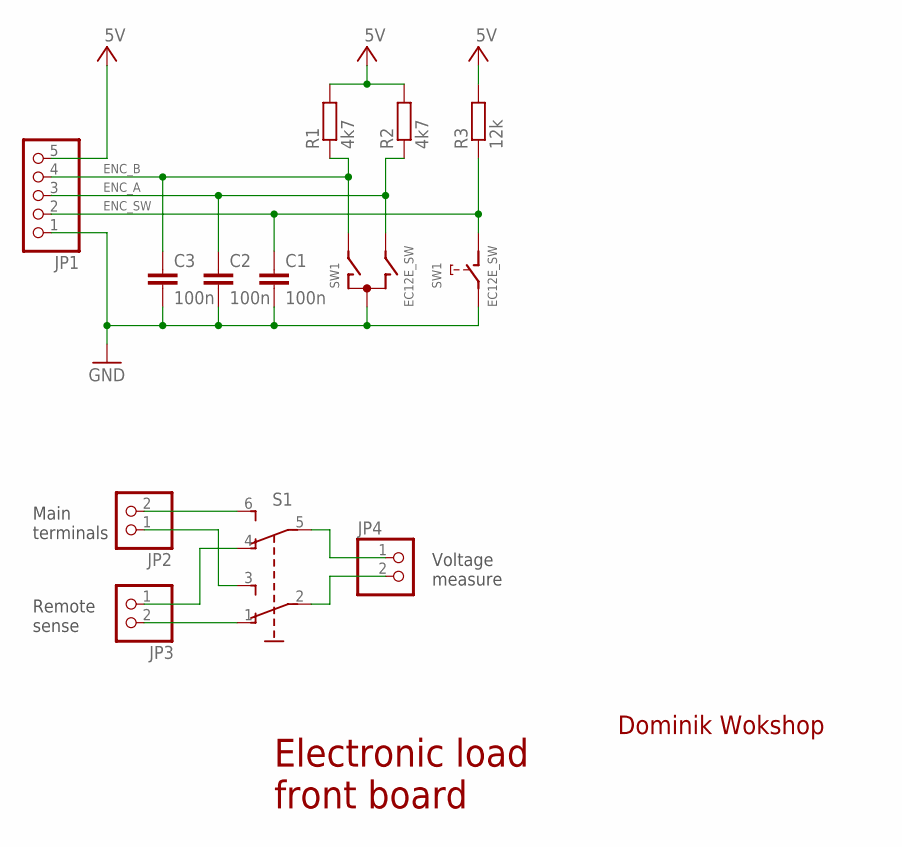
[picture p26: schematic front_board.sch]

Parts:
C1, C2, C3: 100n; C0603
JP1: PINHD-1X5/90; 1X05/90
JP2, JP3, JP4: PINHD-1X2/90; 1X02/90
R1, R2: 4k7; R0603
R3: 12k; R0603
S1: TL46PO; TL4XPO
SW1: EC12E_SW; ALPS_EC12E_SW

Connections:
5V: JP1.5, R1.2, R2.2, R3.2
ENC_A: C2.1, JP1.3, R2.1, SW1.B
ENC_B: C3.1, JP1.4, R1.1, SW1.A
ENC_SW: C1.1, JP1.2, R3.1, SW1.D (1)
GND: C1.2, C2.2, C3.2, JP1.1, SW1.C, SW1.E (2)
unnamed: JP4.2, S1.2
unnamed: JP3.2, S1.1 (O)
unnamed: JP4.1, S1.5 (P1)
unnamed: JP3.1, S1.4 (O1)
unnamed: JP2.1, S1.3 (S)
unnamed: JP2.2, S1.6 (S1)

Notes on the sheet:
Remote sense
Main terminals
Voltage measure
Electronic load front board
Dominik Wokshop

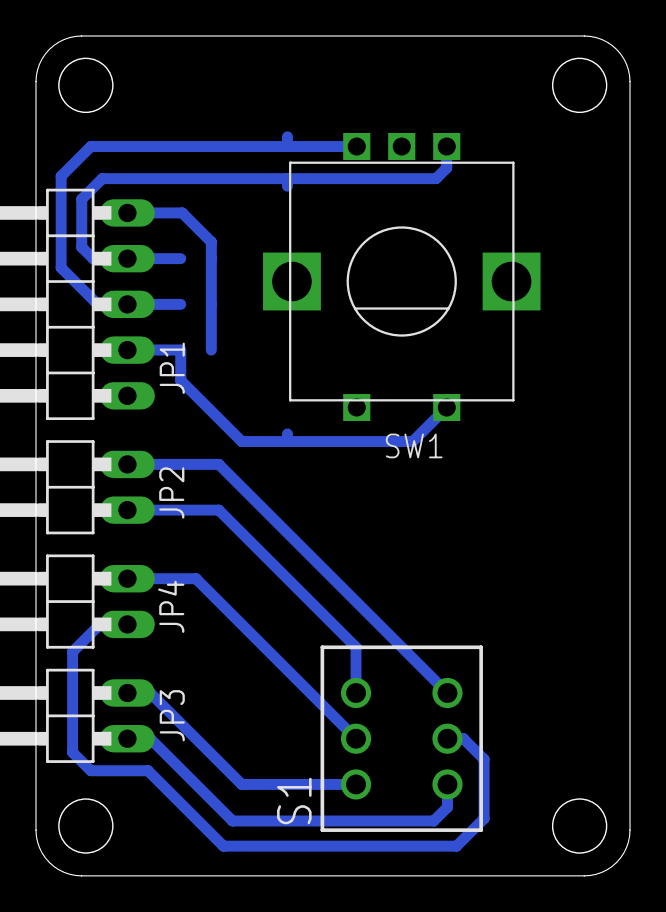
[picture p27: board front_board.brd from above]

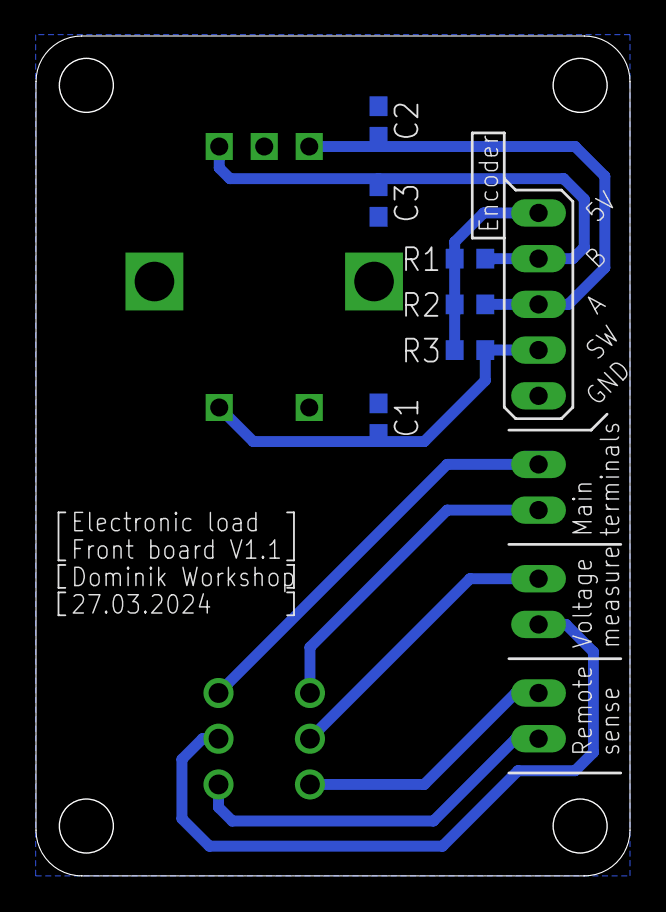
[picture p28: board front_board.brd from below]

Board: 2 copper layers, 33.0 x 46.7 mm, 12 parts (6 on the bottom side), 11 nets.

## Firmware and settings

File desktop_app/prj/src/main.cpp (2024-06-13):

#include "electronic_load_app.h"

#include <QApplication>
#include <QLocale>
#include <QTranslator>
#include <qstylefactory.h>

int main(int argc, char *argv[]){
    QApplication::setStyle(QStyleFactory::create("Fusion"));
    QApplication a(argc, argv);

    QTranslator translator;
    const QStringList uiLanguages = QLocale::system().uiLanguages();
    for (const QString &locale : uiLanguages) {
        const QString baseName = "electronic_load_control_app_" + QLocale(locale).name();
        if (translator.load(":/i18n/" + baseName)) {
            a.installTranslator(&translator);
            break;
        }
    }
    Electronic_load_app w;
    w.show();
    return a.exec();
}

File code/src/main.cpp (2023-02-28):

/**
 * @file main.cpp
 * @author Dominik Workshop
 * @brief Electronic load with 5 different modes of operation:
 *  - Constant current      0,004A - 8,400A,
 *  - Constant power        0,01W - 300,00W,
 *  - Constant resistance   0,1Ω - 9 999,9Ω,
 *  - Transient response
 *  - Battery capacity measurement
 * @version 1.1
 * @date 2022-07-26
 * 
 * @copyright Copyright (c) 2022
 * 
 */

#include <Arduino.h>
#include <Wire.h>
#include <SPI.h>
#include <LiquidCrystal_I2C.h>

#include "defines.hh"
#include "measurements.hh"
#include "controls.hh"
#include "user_input.hh"
#include "lcd_characters.hh"
#include "keypad_config.hh"
#include "encoder.hh"
#include "init.hh"
#include "mode_screen.hh"

int main(void){
/////////Arduino stuff//////////
  init();
  #if defined(USBCON)
    USBDevice.attach();
  #endif
////////////////////////////////

  Measurements measurements;
  Controls controls(measurements);
  UserInput userInput;
  LiquidCrystal_I2C lcd(LCD_ADDRESS, 20, 4);
  Keypad keypad(makeKeymap(hexaKeys), rowPins, colPins, KEYPAD_ROWS, KEYPAD_COLS);
  Encoder encoder;
  Battery battery;
  Transient transient;

  lcd.init();
  lcd.backlight();              //turn the backlight on
  lcd.createChar(degree, degreeSymbol);
  lcd.createChar(ohm, ohmSymbol);
  encoder.begin();

  Serial.begin(9600);

  pinInit();

  controls.loadOff(lcd);

  displayWelcomeScreen(lcd);
  delay(2000);
  displayMenu(lcd);

  for (;;) {  //void loop() equivalent
		switch (keypad.getKey()){
			case '1':
				constCurrentMode(lcd, userInput, keypad, encoder, measurements, controls);
        displayMenu(lcd);
				break;
			case '2':
				constPowerMode(lcd, userInput, keypad, encoder, measurements, controls);
        displayMenu(lcd);
				break;
			case '3':
				constResistanceMode(lcd, userInput, keypad, encoder, measurements, controls);
        displayMenu(lcd);
				break;
			case '4':
				transientResponseMode(lcd, userInput, keypad, encoder, measurements, controls, transient);
        displayMenu(lcd);
				break;
			case '5':
				batteryCapacityMode(lcd, userInput, keypad, encoder, measurements, controls, battery);
        displayMenu(lcd);
				break;
			// case '6':
			// 	calibration(lcd, userInput, keypad, encoder, measurements, controls);
      //  displayMenu(lcd);
			// 	break;
			default:
				delay(10);	//wait 10ms before checking again what keypad was pressed
				break;
		}

    ////////////Arduino stuff/////////////
	  if (serialEventRun) serialEventRun();
    //////////////////////////////////////
	}
  return 0;
}

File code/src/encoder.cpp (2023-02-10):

/**
 * @file encoder.cpp
 * @author Dominik Workshop
 * @brief registers encoder's rotation and based on that increments or decrements a counter, 
 *  detects button press (uses interrupts for both)
 * @version 0.1
 * @date 2022-08-02
 * 
 * @copyright Copyright (c) 2022
 * 
 */

#include "encoder.hh"

Encoder * Encoder::instance;

/**
 * @brief initializes the Encoder, attaches interrupts to appropriate pins
 * 
 */
void Encoder::begin(){
  attachInterrupt(digitalPinToInterrupt(ENCODER_A), isrRotation, FALLING);
  attachInterrupt(digitalPinToInterrupt(ENCODER_BUTTON), isrButton, FALLING);
  instance = this;
}

/**
 * @brief resets both the counter that indicates rotation and a flag that indicates that the Encoder's button was pressed
 * 
 */
void Encoder::reset(){
  counter = 0;
  buttonPressed = false;
}

void Encoder::isrRotation(){
  instance->handleInterruptRotation();
}

void Encoder::isrButton(){
  instance->handleInterruptButton();
}

void Encoder::handleInterruptRotation(){
  static unsigned long lastInterruptTimeRotation = 0;
  unsigned long interruptTime = millis();

  // If interrupts come faster than 5ms, assume it's a bounce and ignore
  if(interruptTime - lastInterruptTimeRotation > 5){
    if(digitalRead(ENCODER_B) == LOW) 
      counter--;
    else 
      counter++;
  }

  lastInterruptTimeRotation = interruptTime;
}

void Encoder::handleInterruptButton(){
  static unsigned long lastInterruptTimeButton = 0;
  unsigned long interruptTime = millis();

  // If interrupts come faster than 100ms, assume it's a bounce and ignore
  if(interruptTime - lastInterruptTimeButton > 100)
    buttonPressed = true;
  
  lastInterruptTimeButton = interruptTime;
}

/**
 * @brief checks if the button was pressed since last time it was checked 
 *  or since last Encoder::reset()
 * 
 * @return true when button was pressed
 * @return false when button wasn't pressed
 */
bool Encoder::wasButtonPressed(){
  if(buttonPressed){
    buttonPressed = false; //reset buttonPressed flag
    return true;
  }
  else
    return false;
}

/**
 * @brief checks how many steps was the encoder rotated since last Encoder::reset()
 * 
 * @return int number of steps, the value increases if rotated clockwise, decreases if rotated anticlockwise
 */
int Encoder::rotation(){
  return counter;
}

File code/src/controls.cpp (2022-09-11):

/**
 * @file controls.cpp
 * @author Dominik Workshop
 * @brief fan, load on/off, current/power/resitance regulation controlls
 * @version 1.1
 * @date 2022-09-08
 * 
 * @copyright Copyright (c) 2022
 * 
 */

#include "controls.hh"

/**
 * @brief initializes DAC and reads calibration values from EEPROM when the object is created
 * 
 */
Controls::Controls(Measurements& measurements_): measurements(measurements_){
	dac.begin(DAC_ADDRESS);
	calibration.readFromEEPROM();
}

/**
 * @brief controls the fan speed depending on measured temperature
 * (with hysteresis)
 * 
 */
void Controls::fanControll(){
	fanspeed = map(measurements.temperature, lowTemperatureThreshold, 45, 60, 255);
	//hysteresis, so that fans don't turn on/off repeatedly when crossing the threshold
  if (measurements.temperature < lowTemperatureThreshold){
    fanspeed = 0;
    lowTemperatureThreshold = 31;
  }
  if (measurements.temperature >= lowTemperatureThreshold)
     lowTemperatureThreshold=30;

  //if it's hot drive fans at full speed
  if (measurements.temperature > 45){
    fanspeed = 255;
	}
	analogWrite(FAN, fanspeed);
}

/**
 * @brief turns the load on and displays "ON " in the upper right corner of the lcd
 * 
 * @param lcd 
 */
void Controls::loadOn(LiquidCrystal_I2C& lcd){
	digitalWrite(OUTPUT_OFF, HIGH);
	lcd.setCursor(17, 0);
	lcd.print("ON ");
	loadIsOn = true;
}

/**
 * @brief turns the load off and displays "OFF" in the upper right corner of the lcd
 * 
 * @param lcd 
 */
void Controls::loadOff(LiquidCrystal_I2C& lcd){
	digitalWrite(OUTPUT_OFF, LOW);
	lcd.setCursor(17, 0);
	lcd.print("OFF");
	loadIsOn = false;
}

/**
 * @brief toggles the load on or off and displays "ON " or "OFF" in the upper right corener of the lcd
 * 
 * @param lcd 
 */
void Controls::loadOnOffToggle(LiquidCrystal_I2C& lcd){
	if(loadIsOn){
		loadOff(lcd);
	}
	else if(!loadIsOn){
		loadOn(lcd);
	}	
}

void Controls::regulateCurrent(float setCurrent){
	if(setCurrent > MAX_CURRENT)
		setCurrent = MAX_CURRENT;
	if(setCurrent * measurements.voltage > MAX_POWER)
		setCurrent = MAX_POWER / measurements.voltage;

								//setCurrent*resolution/Vref*attenuation/equivalent R of shunts * calibrationMultiplier + calibrationOffset
	int dacControl = setCurrent * 4096 / 4.096 / 0.053 * 0.025 * (0.95 + calibration.getSetCurrentMultiplier()/2550.0) + (calibration.getSetCurrentOffset() - 128);
	if(dacControl < 0)						//////////////////////////////
		dacControl = 0;							//	ensure that dacControl	//
	else if(dacControl > 4095)		//	is between 0 and 4095		//
		dacControl = 4095;					//////////////////////////////
	dac.setVoltage(dacControl, false);
}

void Controls::regulatePower(float setPower){
	regulateCurrent(setPower/measurements.voltage);
}

void Controls::regulateResistance(float setResistance){
	regulateCurrent(measurements.voltage/setResistance);
}

bool Controls::isLoadOn(){
	return loadIsOn;
}

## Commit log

2022-07-12 most analog circutry done
    [Electronic_load.brd, Electronic_load.sch]
2022-07-24 Power supply schematic done
    [Electronic_load.brd, Electronic_load.sch]
2022-07-27 calibration class and methods
2022-07-27 initialized adc, dac, lcd, declared calValues
2022-07-27 finished power supply, added keypad, programming connector, transient trigger and more
    [Electronic_load.brd, Electronic_load.sch]
2022-07-28 before voltage reference change
    [Electronic_load.brd, Electronic_load.sch]
2022-07-29 new voltage reference
    [Electronic_load.brd, Electronic_load.sch]
2022-07-31 finished V1.0
    [Electronic_load.brd, Electronic_load.sch]
2022-07-31 added missing 3d models
    [Electronic_load.brd, Electronic_load.sch]
2022-08-01 thermistor temperature measurement
2022-08-01 keypad, encoder, and thermistor
2022-08-01 encoder v1
2022-08-01 encoder init
2022-08-01 temperature and encoder test
2022-08-01 encoder class with interrupt
2022-08-01 new encoder class tested
2022-08-01 9 pin keypad
2022-08-02 added encoder button
2022-08-02 encoder rotation and button tested
2022-08-04 finished V1
    [Electronic_load_front_PCB.brd, Electronic_load_front_PCB.sch]
2022-08-05 new parts list
    [Electronic_load_BOM.csv]
2022-08-05 added missing component values
    [Electronic_load.brd, Electronic_load.sch]
2022-08-05 change value with encoder after key press
2022-08-06 UserInput containing encoder and keypad
2022-08-06 seperate set variables, removed encoder and keypad
2022-08-06 fixed some input bugs
    [mode_screen.cpp]
2022-08-06 Encoder and Keypad separated from UserInput
2022-08-07 encoder switches decimal places
2022-08-07 display cursor pos (in resistance mode)
2022-08-08 moving average filter
2022-08-19 changed encoder pin for pcb
2022-08-19 reversed encoder rotation
2022-08-19 changed for pcb
2022-08-20 changed some resistor values
    [Electronic_load.brd, Electronic_load.sch]
2022-08-23 cleaned up schematic
    [Electronic_load.brd, Electronic_load.sch]
2022-08-29 rename folder
    [Electronic_load_front_PCB.brd]
2022-08-29 renamed folder
    [Electronic_load.brd, Electronic_load.sch]
2022-08-29 passed adc, dac objects
2022-08-29 program via uart
2022-08-29 mount fits
    [arduino_holder.stl]
2022-08-31 finished v1 printed
    [front_pannel.stl]
2022-09-02 height and holes adjusted
    [arduino_holder.stl]
2022-09-05 measurements in cons resistance
2022-09-06 set current added
2022-09-08 temperature moved to measurements
2022-09-08 temperature, calibration
2022-09-08 calibration, fan controll
2022-09-08 separate class for adc and dac calibration
2022-09-08 calibration, measurements
2022-09-08 offset current calibration
2022-09-08 change displayed power precision >=100W
2022-09-08 zero current when off, (getters setters cal)
2022-09-08 fan control, on/off
2022-09-09 adc moved to measurements
2022-09-09 controls class, power and resistance mode working
2022-09-09 load off on power up
2022-09-09 crude dac calibration
2022-09-09 timer library
2022-09-09 timer added
2022-09-09 cal, timer test
2022-09-09 current sink adjusted to new voltage divider
2022-09-09 power limiting test
2022-09-09 removed voltage parameter passed to functions
2022-09-09 4mA min current
2022-09-09 dac offset calibration
2022-09-09 zero out current and power when load off
2022-09-10 button debounce
2022-09-11 rename current, power, resistance regulation func
2022-09-11 calibration finished
2022-09-11 voltage with 3 decimals <10V
2022-09-12 began working on battery mode
2022-09-25 rotation doesn't print to lcd
    [user_input.cpp]
2022-09-25 battery mode timer, encoder rotoration works
2022-09-25 added measured voltage offset calibration
2022-09-25 keypad works in battery mode
2022-09-26 battery capacity measurement works
2022-09-26 cutoff edit, display capacity method
2022-09-27 cutoff works in battery mode
2022-09-27 capacity considering changes in current
2022-10-01 cleanup after debug and fix memory leak
    [main.cpp, mode_screen.cpp]
2022-10-01 battery mode finished?
2022-10-02 battery and transient instances moved to main()
2022-10-02 toggling between set variables resets timer
    [mode_screen.cpp]
2022-10-05 fix max voltage
2022-10-13 schematic pdf
2023-02-10 encoder works great, bounces reduced
    [Electronic_load_front_PCB.brd, Electronic_load_front_PCB.sch]
2023-02-28 disable calibration mode
2023-11-05 added C10, schematic minor updates
    [Electronic_load.brd, Electronic_load.sch, Electronic_load_BOM.csv]
2024-03-27 gerber files
2024-03-27 rm bom
    [Electronic_load_BOM.csv]
2024-04-08 update R22 value
    [Electronic_load.brd, Electronic_load.sch]
2024-06-13 fix text alignement, capacity digits
2024-10-26 Add missing component designators on schematic, adjust text size and positioning
    [Electronic_load.brd, Electronic_load.sch]
2024-10-26 Improve schematic, adjust text size and positioning
    [Electronic_load.brd, Electronic_load.sch]
2024-11-05 Add more renders of the enclosure
2024-11-05 Improve PCB renders
2024-11-05 Ajust scale and positioning of front PCB render in README
2024-11-06 Improve schematic slightly
    [front_board.sch]
2024-11-30 Rename CURRENTx nets to V_SHUNT_x, add negation to OFF net on the main pcb
    [Electronic_load.brd, Electronic_load.sch]
2025-02-25 Reverse calibration order: first offset then multiplier
    [mode_screen.cpp]
2025-03-17 Add voltage and current accuracy measurements results to README
    Add voltage and current accuracy measurements results to README
